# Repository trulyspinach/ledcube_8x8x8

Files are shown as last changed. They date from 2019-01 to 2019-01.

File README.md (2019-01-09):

# ledcube_8x8x8

Hobby Compact LED Cube.

Please beware that I'm not a professional electrical enginner, this project is just me having fun. I provide absolutely no warranty for this :)

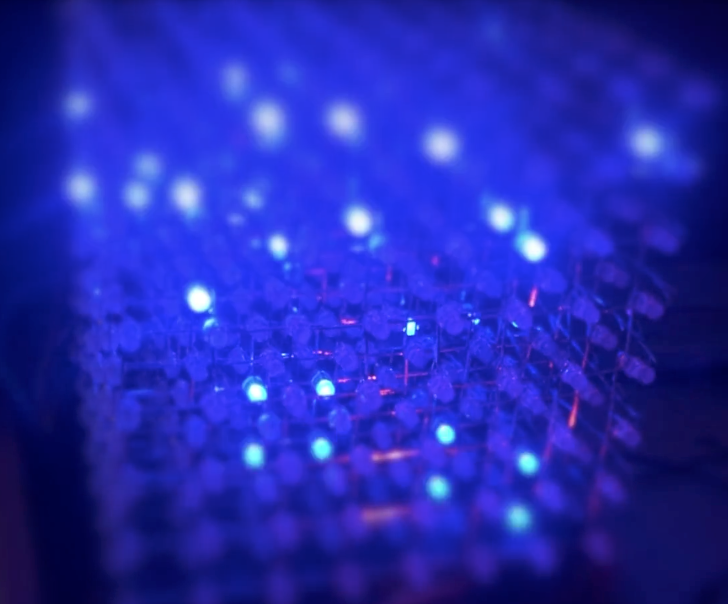
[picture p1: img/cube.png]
cover


## The hardware build

My goal is to build a compact LED cube. A lot of cube built i found on Internet is huge(kind of, at least you can't carry them with you), even when the resolution is 8x8x8. So I chose to use small LEDs, and a printed circuit board to hold them together while providing control circuits.

The microcontroller is Atmega32A, the reason of choosing AVR is just because they are simple and really cheap to get, and the 32A model have a fairly enough amount of pins available. Then eight 574s are used for multiplexing IOs. No big deals, pretty simple.

To build this, all you need is around 6 hundreds of LEDs. Only 512 are needed, but when you purchasing cheap LEDs, it is likely that some of them will malfunctions. And some resisitor, caps for the motherboard.

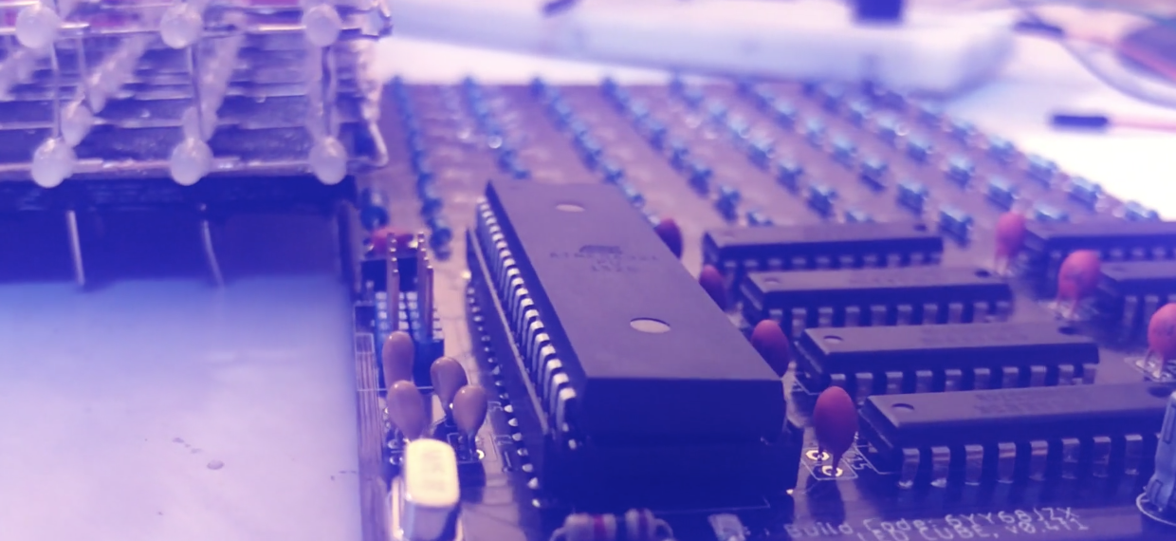
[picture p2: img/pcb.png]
pcb


I got all components on local stores and AliExpress, the complete built cost me less than $10(surprisingly cheap huh?).

## Software.

Well, since it is an Atmega32A, you can totaly program it using Arduino IDE(You don't need to).
I haven't had enough time to write some beautiful program yet, but the demo code included is just enough to test and proof your circuit is working.

Yes I will put more code here later..

## Did I made a video ?

Yes, it is here: https://www.bilibili.com/video/av40196289/

The voiceover is me speaking Chinese, but it should be fine.

## Where to get PCBs?

I did included all board layout file in the repo, you can export them with Eagle to some manufactor to made them.
As you know, those manufactors don't really like to just make one board, so I have some spare boards in my hand. I can ship one to you if you live in China, and if by the time you contact me I still have them..

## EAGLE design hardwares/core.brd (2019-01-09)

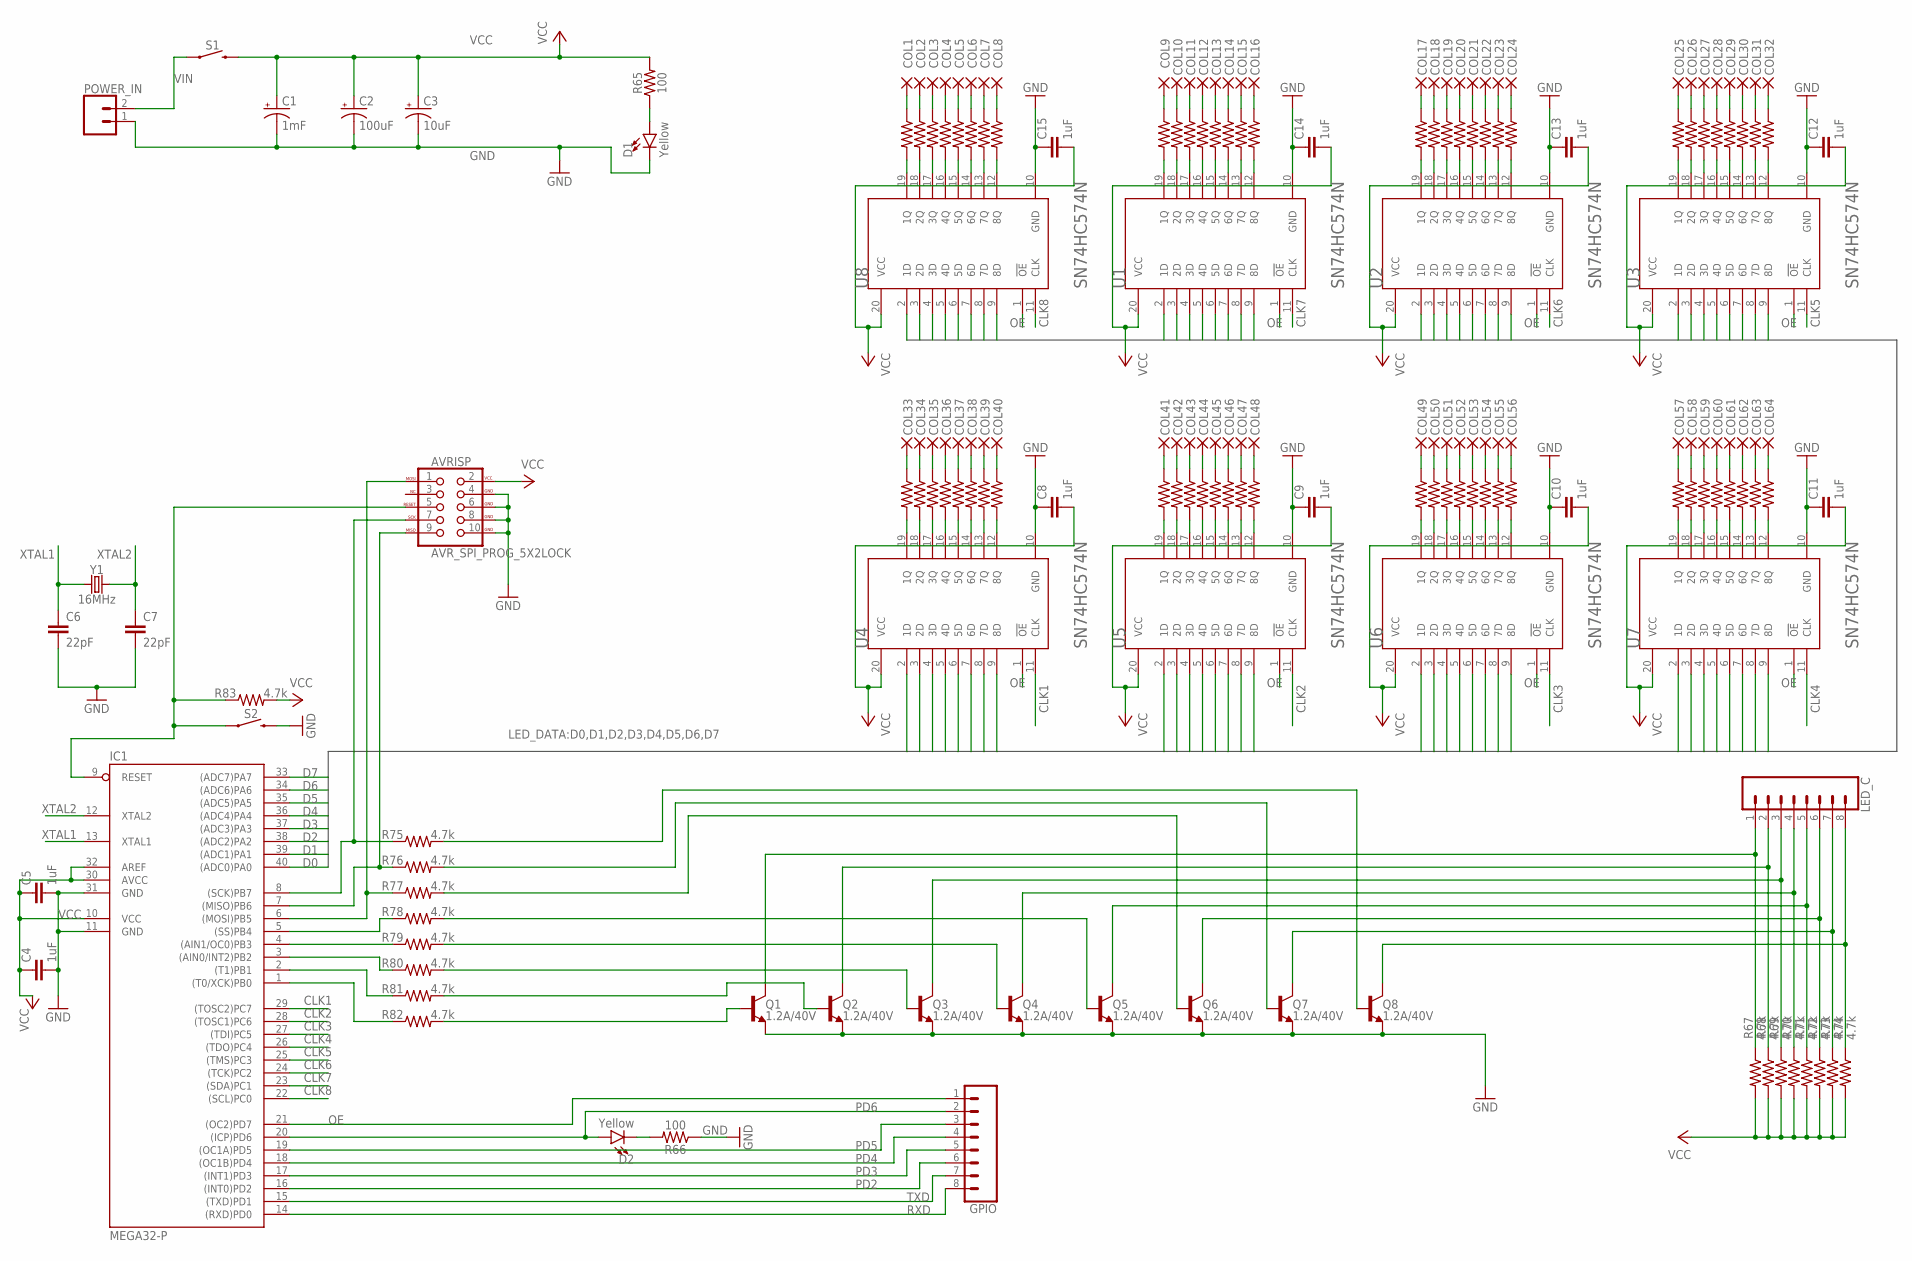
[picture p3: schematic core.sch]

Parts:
AVRISP: AVR_SPI_PROG_5X2LOCK; 2X5-SHROUDED_LOCK
C1: 1mF; CPOL-RADIAL-5MM-10MM
C2: 100uF; CPOL-RADIAL-2.5MM-6.5MM
C3: 10uF; CPOL-RADIAL-2.5MM-5MM
C4, C5, C8, C9, C10, C11, C12, C13, C14, C15: 1uF; C2.5-3
C6, C7: 22pF; CAP-PTH-2.54
COL1, COL2, COL3, COL4, COL5, COL6, COL7, COL8, COL9, COL10, COL11, COL12, COL13, COL14, COL15, COL16, COL17, COL18, COL19, COL20, COL21, COL22, COL23, COL24, COL25, COL26, COL27, COL28, COL29, COL30, COL31, COL32, COL33, COL34, COL35, COL36, COL37, COL38, COL39, COL40, COL41, COL42, COL43, COL44, COL45, COL46, COL47, COL48, COL49, COL50, COL51, COL52, COL53, COL54, COL55, COL56, COL57, COL58, COL59, COL60, COL61, COL62, COL63, COL64: 1,6/0,9
D1, D2: Yellow; LED-1206
GPIO: CONN_08"; 1X08
IC1: MEGA32-P; DIL40
LED_C: CONN_08"; 1X08
POWER_IN: CONN_02POLAR; MOLEX-1X2
Q1, Q2, Q3, Q4, Q5, Q6, Q7, Q8: 1.2A/40V; SOT23-3
R1, R2, R3, R4, R5, R6, R7, R8, R9, R10, R11, R12, R13, R14, R15, R16, R17, R18, R19, R20, R21, R22, R23, R24, R25, R26, R27, R28, R29, R30, R31, R32, R33, R34, R35, R36, R37, R38, R39, R40, R41, R42, R43, R44, R45, R46, R47, R48, R49, R50, R51, R52, R53, R54, R55, R56, R57, R58, R59, R60, R61, R62, R63, R64, R65, R66: 100; AXIAL-0.3
R67, R68, R69, R70, R71, R72, R73, R74, R75, R76, R77, R78, R79, R80, R81, R82, R83: 4.7k; AXIAL-0.3
S1: MOMENTARY-SWITCH-SPST-PTH-RIGHT-ANGLE-KIT; TACTILE_SWITCH_PTH_RIGHT_ANGLE_KIT
S2: MOMENTARY-SWITCH-SPST-PTH-6.0MM; TACTILE_SWITCH_PTH_6.0MM
U1, U2, U3, U4, U5, U6, U7, U8: TEXAS_INSTRUMENTS_SN74HC574NTEXAS_INSTRUMENTS_SN7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; TEXAS_INSTRUMENTS_SN74HC574N_0
Y1: 16MHz; HC49US

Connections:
CLK1: IC1.29 ((TOSC2)PC7), U4.11 (CLK)
CLK2: IC1.28 ((TOSC1)PC6), U5.11 (CLK)
CLK3: IC1.27 ((TDI)PC5), U6.11 (CLK)
CLK4: IC1.26 ((TDO)PC4), U7.11 (CLK)
CLK5: IC1.25 ((TMS)PC3), U3.11 (CLK)
CLK6: IC1.24 ((TCK)PC2), U2.11 (CLK)
CLK7: IC1.23 ((SDA)PC1), U1.11 (CLK)
CLK8: IC1.22 ((SCL)PC0), U8.11 (CLK)
D0: IC1.40 ((ADC0)PA0), U1.2 (1D), U2.2 (1D), U3.2 (1D), U4.2 (1D), U5.2 (1D), U6.2 (1D), U7.2 (1D), U8.2 (1D)
D1: IC1.39 ((ADC1)PA1), U1.3 (2D), U2.3 (2D), U3.3 (2D), U4.3 (2D), U5.3 (2D), U6.3 (2D), U7.3 (2D), U8.3 (2D)
D2: IC1.38 ((ADC2)PA2), U1.4 (3D), U2.4 (3D), U3.4 (3D), U4.4 (3D), U5.4 (3D), U6.4 (3D), U7.4 (3D), U8.4 (3D)
D3: IC1.37 ((ADC3)PA3), U1.5 (4D), U2.5 (4D), U3.5 (4D), U4.5 (4D), U5.5 (4D), U6.5 (4D), U7.5 (4D), U8.5 (4D)
D4: IC1.36 ((ADC4)PA4), U1.6 (5D), U2.6 (5D), U3.6 (5D), U4.6 (5D), U5.6 (5D), U6.6 (5D), U7.6 (5D), U8.6 (5D)
D5: IC1.35 ((ADC5)PA5), U1.7 (6D), U2.7 (6D), U3.7 (6D), U4.7 (6D), U5.7 (6D), U6.7 (6D), U7.7 (6D), U8.7 (6D)
D6: IC1.34 ((ADC6)PA6), U1.8 (7D), U2.8 (7D), U3.8 (7D), U4.8 (7D), U5.8 (7D), U6.8 (7D), U7.8 (7D), U8.8 (7D)
D7: IC1.33 ((ADC7)PA7), U1.9 (8D), U2.9 (8D), U3.9 (8D), U4.9 (8D), U5.9 (8D), U6.9 (8D), U7.9 (8D), U8.9 (8D)
GND: AVRISP.4 (GND), AVRISP.6 (GND), AVRISP.8 (GND), AVRISP.10 (GND), C1.-, C2.2 (-), C3.2 (-), C4.2, C5.2, C6.2, C7.2, C8.1, C9.1, C10.1, C11.1, C12.1, C13.1, C14.1, C15.1, D1.C, IC1.11 (GND), IC1.31 (GND), POWER_IN.1, Q1.2 (E), Q2.2 (E), Q3.2 (E), Q4.2 (E), Q5.2 (E), Q6.2 (E), Q7.2 (E), Q8.2 (E), R66.P$1 (1), S2.3 (2), U1.10 (GND), U2.10 (GND), U3.10 (GND), U4.10 (GND), U5.10 (GND), U6.10 (GND), U7.10 (GND), U8.10 (GND)
unnamed: COL1.1, R1.P$1 (1)
unnamed: R1.P$2 (2), U8.19 (1Q)
unnamed: COL2.1, R2.P$1 (1)
unnamed: R2.P$2 (2), U8.18 (2Q)
unnamed: COL3.1, R3.P$1 (1)
unnamed: R3.P$2 (2), U8.17 (3Q)
unnamed: COL4.1, R4.P$1 (1)
unnamed: R4.P$2 (2), U8.16 (4Q)
unnamed: COL5.1, R5.P$1 (1)
unnamed: R5.P$2 (2), U8.15 (5Q)
unnamed: COL6.1, R6.P$1 (1)
unnamed: R6.P$2 (2), U8.14 (6Q)
unnamed: COL7.1, R7.P$1 (1)
unnamed: R7.P$2 (2), U8.13 (7Q)
unnamed: COL8.1, R8.P$1 (1)
unnamed: R8.P$2 (2), U8.12 (8Q)
unnamed: COL9.1, R9.P$1 (1)
unnamed: R9.P$2 (2), U1.19 (1Q)
unnamed: COL10.1, R10.P$1 (1)
unnamed: R10.P$2 (2), U1.18 (2Q)
unnamed: COL11.1, R11.P$1 (1)
unnamed: R11.P$2 (2), U1.17 (3Q)
unnamed: COL12.1, R12.P$1 (1)
unnamed: R12.P$2 (2), U1.16 (4Q)
unnamed: COL13.1, R13.P$1 (1)
unnamed: R13.P$2 (2), U1.15 (5Q)
unnamed: COL14.1, R14.P$1 (1)
unnamed: R14.P$2 (2), U1.14 (6Q)
unnamed: COL15.1, R15.P$1 (1)
unnamed: R15.P$2 (2), U1.13 (7Q)
unnamed: COL16.1, R16.P$1 (1)
unnamed: R16.P$2 (2), U1.12 (8Q)
unnamed: COL17.1, R17.P$1 (1)
unnamed: R17.P$2 (2), U2.19 (1Q)
unnamed: COL18.1, R18.P$1 (1)
unnamed: R18.P$2 (2), U2.18 (2Q)
unnamed: COL19.1, R19.P$1 (1)
unnamed: R19.P$2 (2), U2.17 (3Q)
unnamed: COL20.1, R20.P$1 (1)
unnamed: R20.P$2 (2), U2.16 (4Q)
unnamed: COL21.1, R21.P$1 (1)
unnamed: R21.P$2 (2), U2.15 (5Q)
unnamed: COL22.1, R22.P$1 (1)
unnamed: R22.P$2 (2), U2.14 (6Q)
unnamed: COL23.1, R23.P$1 (1)
unnamed: R23.P$2 (2), U2.13 (7Q)
unnamed: COL24.1, R24.P$1 (1)
unnamed: R24.P$2 (2), U2.12 (8Q)
unnamed: COL25.1, R25.P$1 (1)
unnamed: R25.P$2 (2), U3.19 (1Q)
unnamed: COL26.1, R26.P$1 (1)
unnamed: R26.P$2 (2), U3.18 (2Q)
unnamed: COL27.1, R27.P$1 (1)
unnamed: R27.P$2 (2), U3.17 (3Q)
unnamed: COL28.1, R28.P$1 (1)
unnamed: R28.P$2 (2), U3.16 (4Q)
unnamed: COL29.1, R29.P$1 (1)
unnamed: R29.P$2 (2), U3.15 (5Q)
unnamed: COL30.1, R30.P$1 (1)
unnamed: R30.P$2 (2), U3.14 (6Q)
unnamed: COL31.1, R31.P$1 (1)
unnamed: R31.P$2 (2), U3.13 (7Q)
unnamed: COL32.1, R32.P$1 (1)
unnamed: R32.P$2 (2), U3.12 (8Q)
unnamed: COL33.1, R33.P$1 (1)
unnamed: R33.P$2 (2), U4.19 (1Q)
unnamed: COL34.1, R34.P$1 (1)
unnamed: R34.P$2 (2), U4.18 (2Q)
unnamed: COL35.1, R35.P$1 (1)
unnamed: R35.P$2 (2), U4.17 (3Q)
unnamed: COL36.1, R36.P$1 (1)
unnamed: R36.P$2 (2), U4.16 (4Q)
unnamed: COL37.1, R37.P$1 (1)
unnamed: R37.P$2 (2), U4.15 (5Q)
unnamed: COL38.1, R38.P$1 (1)
unnamed: R38.P$2 (2), U4.14 (6Q)
unnamed: COL39.1, R39.P$1 (1)
unnamed: R39.P$2 (2), U4.13 (7Q)
unnamed: COL40.1, R40.P$1 (1)
unnamed: R40.P$2 (2), U4.12 (8Q)
unnamed: COL41.1, R41.P$1 (1)
unnamed: R41.P$2 (2), U5.19 (1Q)
unnamed: COL42.1, R42.P$1 (1)
unnamed: R42.P$2 (2), U5.18 (2Q)
unnamed: COL43.1, R43.P$1 (1)
unnamed: R43.P$2 (2), U5.17 (3Q)
unnamed: COL44.1, R44.P$1 (1)
unnamed: R44.P$2 (2), U5.16 (4Q)
unnamed: COL45.1, R45.P$1 (1)
unnamed: R45.P$2 (2), U5.15 (5Q)
unnamed: COL46.1, R46.P$1 (1)
unnamed: R46.P$2 (2), U5.14 (6Q)
unnamed: COL47.1, R47.P$1 (1)
unnamed: R47.P$2 (2), U5.13 (7Q)
unnamed: COL48.1, R48.P$1 (1)
unnamed: R48.P$2 (2), U5.12 (8Q)
unnamed: COL49.1, R49.P$1 (1)
unnamed: R49.P$2 (2), U6.19 (1Q)
unnamed: COL50.1, R50.P$1 (1)
unnamed: R50.P$2 (2), U6.18 (2Q)
unnamed: COL51.1, R51.P$1 (1)
unnamed: R51.P$2 (2), U6.17 (3Q)
unnamed: COL52.1, R52.P$1 (1)
unnamed: R52.P$2 (2), U6.16 (4Q)
unnamed: COL53.1, R53.P$1 (1)
unnamed: R53.P$2 (2), U6.15 (5Q)
unnamed: COL54.1, R54.P$1 (1)
unnamed: R54.P$2 (2), U6.14 (6Q)
unnamed: COL55.1, R55.P$1 (1)
unnamed: R55.P$2 (2), U6.13 (7Q)
unnamed: COL56.1, R56.P$1 (1)
unnamed: R56.P$2 (2), U6.12 (8Q)
unnamed: COL57.1, R57.P$1 (1)
unnamed: R57.P$2 (2), U7.19 (1Q)
unnamed: COL58.1, R58.P$1 (1)
unnamed: R58.P$2 (2), U7.18 (2Q)
unnamed: COL59.1, R59.P$1 (1)
unnamed: R59.P$2 (2), U7.17 (3Q)
unnamed: COL60.1, R60.P$1 (1)
unnamed: R60.P$2 (2), U7.16 (4Q)
unnamed: COL61.1, R61.P$1 (1)
unnamed: R61.P$2 (2), U7.15 (5Q)
unnamed: COL62.1, R62.P$1 (1)
unnamed: R62.P$2 (2), U7.14 (6Q)
unnamed: COL63.1, R63.P$1 (1)
unnamed: R63.P$2 (2), U7.13 (7Q)
unnamed: COL64.1, R64.P$1 (1)
unnamed: R64.P$2 (2), U7.12 (8Q)
unnamed: D1.A, R65.P$1 (1)
unnamed: D2.C, R66.P$2 (2)
unnamed: LED_C.1, Q1.3 (C), R67.P$1 (1)
unnamed: LED_C.2, Q2.3 (C), R68.P$1 (1)
unnamed: LED_C.3, Q3.3 (C), R69.P$1 (1)
unnamed: LED_C.4, Q4.3 (C), R70.P$1 (1)
unnamed: LED_C.5, Q5.3 (C), R71.P$1 (1)
unnamed: LED_C.6, Q6.3 (C), R72.P$1 (1)
unnamed: LED_C.7, Q7.3 (C), R73.P$1 (1)
unnamed: LED_C.8, Q8.3 (C), R74.P$1 (1)
unnamed: IC1.1 ((T0/XCK)PB0), R82.P$1 (1)
unnamed: IC1.2 ((T1)PB1), R81.P$1 (1)
unnamed: IC1.3 ((AIN0/INT2)PB2), R80.P$1 (1)
unnamed: IC1.4 ((AIN1/OC0)PB3), R79.P$1 (1)
unnamed: IC1.5 ((SS)PB4), R78.P$1 (1)
unnamed: AVRISP.1 (MOSI), IC1.6 ((MOSI)PB5), R77.P$1 (1)
unnamed: AVRISP.9 (MISO), IC1.7 ((MISO)PB6), R76.P$1 (1)
unnamed: AVRISP.7 (SCK), IC1.8 ((SCK)PB7), R75.P$1 (1)
unnamed: Q1.1 (B), R82.P$2 (2)
unnamed: Q2.1 (B), R81.P$2 (2)
unnamed: Q6.1 (B), R77.P$2 (2)
unnamed: Q3.1 (B), R80.P$2 (2)
unnamed: Q4.1 (B), R79.P$2 (2)
unnamed: Q5.1 (B), R78.P$2 (2)
unnamed: Q7.1 (B), R76.P$2 (2)
unnamed: Q8.1 (B), R75.P$2 (2)
unnamed: AVRISP.5 (RESET), IC1.9 (RESET), R83.P$1 (1), S2.1
OE: GPIO.1, IC1.21 ((OC2)PD7), U1.1 (!OE!), U2.1 (!OE!), U3.1 (!OE!), U4.1 (!OE!), U5.1 (!OE!), U6.1 (!OE!), U7.1 (!OE!), U8.1 (!OE!)
PD2: GPIO.6, IC1.16 ((INT0)PD2)
PD3: GPIO.5, IC1.17 ((INT1)PD3)
PD4: GPIO.4, IC1.18 ((OC1B)PD4)
PD5: GPIO.3, IC1.19 ((OC1A)PD5)
PD6: D2.A, GPIO.2, IC1.20 ((ICP)PD6)
RXD: GPIO.8, IC1.14 ((RXD)PD0)
TXD: GPIO.7, IC1.15 ((TXD)PD1)
VCC: AVRISP.2 (VCC), C1.+, C2.1 (+), C3.1 (+), C4.1, C5.1, C8.2, C9.2, C10.2, C11.2, C12.2, C13.2, C14.2, C15.2, IC1.10 (VCC), IC1.30 (AVCC), IC1.32 (AREF), R65.P$2 (2), R67.P$2 (2), R68.P$2 (2), R69.P$2 (2), R70.P$2 (2), R71.P$2 (2), R72.P$2 (2), R73.P$2 (2), R74.P$2 (2), R83.P$2 (2), S1.2, U1.20 (VCC), U2.20 (VCC), U3.20 (VCC), U4.20 (VCC), U5.20 (VCC), U6.20 (VCC), U7.20 (VCC), U8.20 (VCC)
VIN: POWER_IN.2, S1.1
XTAL1: C6.1, IC1.13 (XTAL1), Y1.1
XTAL2: C7.1, IC1.12 (XTAL2), Y1.2

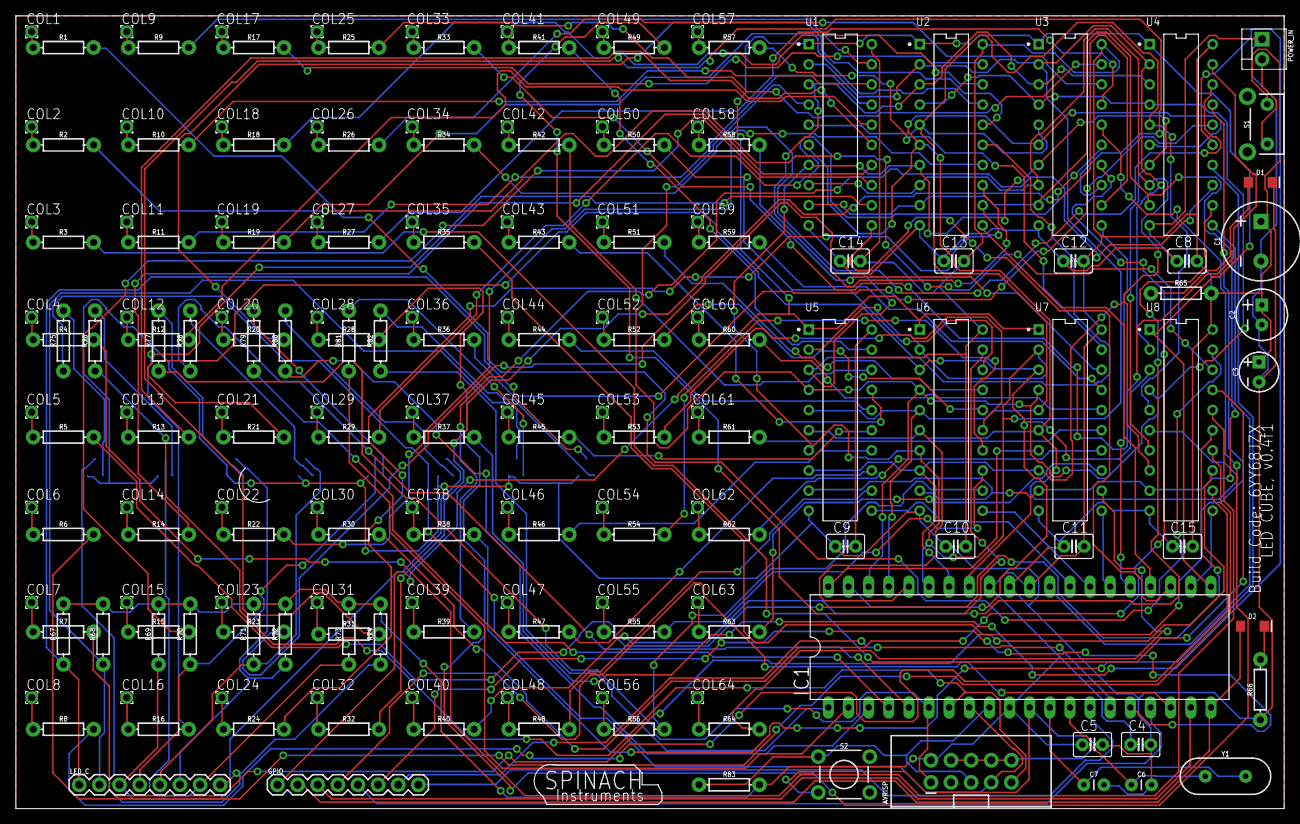
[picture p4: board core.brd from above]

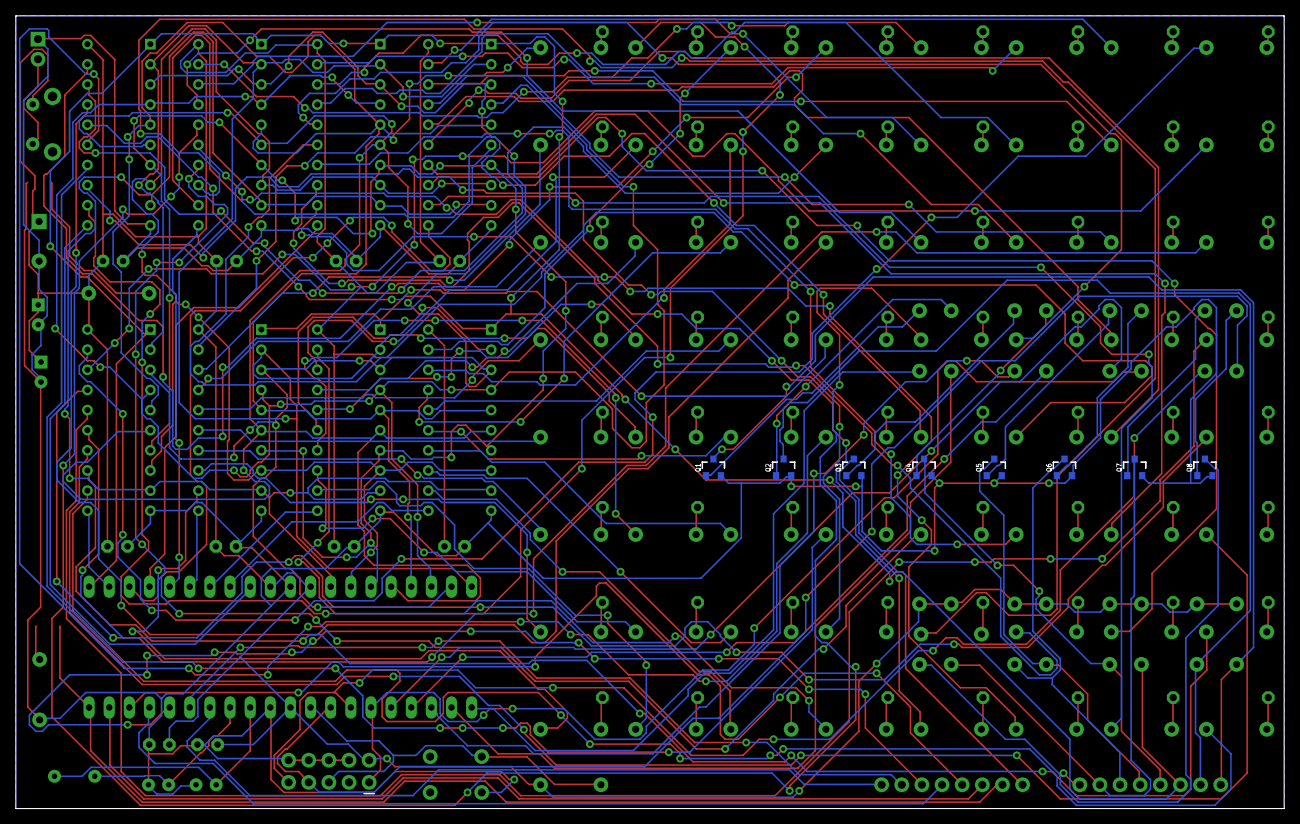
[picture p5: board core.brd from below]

Board: 2 copper layers, 160.0 x 100.0 mm, 188 parts (8 on the bottom side), 184 nets.

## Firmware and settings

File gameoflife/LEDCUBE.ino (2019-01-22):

extern "C"
{
  #include "cube.h"
  #include "cube_graphics.h"
  #include "gameoflife.h"
}


void setup() {
  pinMode(14, OUTPUT);
  pinMode(15, OUTPUT);

  randomSeed(analogRead(0));

  flash_startup_indic();

  init_cube();

  Serial.begin(115200);
  //Set default brightness for cube.
  //analogWrite(15, 210);


  Serial.println("Cube alive!");
  // noise_on();
  // noise_off();
  //
  // rain();

  rand_gen();
  //test_two();
}

void loop(){
  tick();
  //delay(200);
}

void print_coor(uint8_t x, uint8_t y, uint8_t z){
  Serial.print(x);
  Serial.print(", ");
  Serial.print(y);
  Serial.print(", ");
  Serial.println(z);
}



//########## Effects ###########




void voxel_test(){

  Serial.println("voxel test");

  fill_vram();
  uint8_t x = 0;
  uint8_t y = 0;
  uint8_t z = 0;

  bool s_reset = true;

  while(1){
    if(s_reset == false && x == 7 && y == 7 && z == 7) break;
    if(s_reset) reset_voxel(x++,y,z);
    else set_voxel(x++, y, z);
    if(x >= 8){x = 0; y++;}
    if(y >= 8){y = 0; z++;}
    if(z >= 8){z = 0; s_reset = !s_reset;}
    delay(2);

  }
}

void voxel_test_bit(){
  uint16_t remain = 0;

  Serial.println("bit test");
  reset_vram();

  while(remain < 512){
    vram_bit_set(remain++);
    //Serial.println(vram_bit_get(remain++));
    delay(2);
  }
}

void noise_on(){
  reset_vram();
  uint16_t rmn = 512;

  while(rmn > 0){
    uint16_t t_offset = random(1,rmn--);
    uint16_t t_c = 0; uint16_t index = 0;
    while(t_c != t_offset){
       if(vram_bit_get(index++)) continue;
       t_c++;
    }
    vram_bit_set(index - 1);

    //delay(2);
  }
}



void noise_off(){
  uint16_t rmn = 512;

  while(rmn > 0){
    uint16_t t_offset = random(1,rmn--);
    uint16_t t_c = 0; uint16_t index = 0;
    while(t_c != t_offset){
       if(!vram_bit_get(index++)) continue;
       t_c++;
    }
    vram_bit_reset(index - 1);

    //delay(2);
  }
}

void rain(){
  reset_vram();
  uint8_t t = 50;
  while(t-- > 0){
    for(uint8_t i = 0; i < 8; i++)
      vram[i] = 0x00;

    random_on(random(1,8),64);
    vram_shift_down();

    delay(60);
  }

}

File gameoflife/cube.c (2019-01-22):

#include <arduino.h>
#include <avr/io.h>
#include <avr/interrupt.h>
#include <stdbool.h>

#include "cube.h"

uint8_t default_vram[64] = {
  0xff, 0xff, 0xff, 0xff, 0xff, 0xff, 0xff, 0xff,
  0xff, 0xff, 0xff, 0xff, 0xff, 0xff, 0xff, 0xff,
  0xff, 0xff, 0xff, 0xff, 0xff, 0xff, 0xff, 0xff,
  0xff, 0xff, 0xff, 0xff, 0xff, 0xff, 0xff, 0xff,
  0xff, 0xff, 0xff, 0xff, 0xff, 0xff, 0xff, 0xff,
  0xff, 0xff, 0xff, 0xff, 0xff, 0xff, 0xff, 0xff,
  0xff, 0xff, 0xff, 0xff, 0xff, 0xff, 0xff, 0xff,
  0xff, 0xff, 0xff, 0xff, 0xff, 0xff, 0xff, 0xff
};

uint8_t* vram;

uint8_t vram_addr_map[8] = {
  0x01, 0x02, 0x04, 0x08, 0x80, 0x40, 0x20, 0x10
};

//########## Cube refresh routine. ##########

void init_vram(){
  vram = default_vram;
}

void swap_vram(uint8_t ram){
  vram = ram;
}

void setup_refresh_task(){
  TCCR1A = 0x0;
  TCCR1B = 0x3 | _BV(WGM12);
  OCR1A = 0xff;
  TIMSK |= _BV(OCIE1A);

  sei();
}

uint8_t cur_layer = 0;
//Timer interrupt routine to switch layers at constant time interval.
ISR(TIMER1_COMPA_vect){
  PORTC = 0x00;
  for(uint8_t i = 0; i < 8; i++){
    PORTA = vram[cur_layer * 8 + i];
    delayMicroseconds(1);
    PORTC = vram_addr_map[i];
    delayMicroseconds(1);
    PORTC = 0x00;
  }

  PORTB = 1 << cur_layer;
  delayMicroseconds(70);
  PORTB = 0;

  cur_layer++;
  if(cur_layer >= 8) cur_layer = 0;

}

//########## Cube refresh routine. ##########

//########## Low level graphic. #########

void g_set_voxel(uint8_t* ram, uint8_t x, uint8_t y, uint8_t z){
  uint8_t addr = (z % 8) * 8 + (y % 8);
  ram[addr] |= 1 << (x % 8);
}

void g_reset_voxel(uint8_t* ram, uint8_t x, uint8_t y, uint8_t z){
  uint8_t addr = (z % 8) * 8 + (y % 8);
  ram[addr] &= ~(1 << (x % 8));
}

uint8_t g_get_voxel(uint8_t* ram, uint8_t x, uint8_t y, uint8_t z){
  uint8_t addr = (z % 8) * 8 + (y % 8);
  return (ram[addr] >> x) & 0x01;
}

void set_voxel(uint8_t x, uint8_t y, uint8_t z){
  g_set_voxel(vram, x, y, z);
}

void reset_voxel(uint8_t x, uint8_t y, uint8_t z){
  g_reset_voxel(vram, x, y, z);
}

uint8_t get_voxel(uint8_t x, uint8_t y, uint8_t z){
  uint8_t res = g_get_voxel(vram, x, y, z);
  return res;
}

void reset_vram(){
  for(uint8_t i = 0; i < 64; i++)
    vram[i] = 0x00;
}

void fill_vram(){
  for(uint8_t i = 0; i < 64; i++)
    vram[i] = 0xff;
}

void vram_bit_set(uint16_t index){
  set_voxel(index % 8, (index % 64) / 8, index / 64);
}

void vram_bit_reset(uint16_t index){
  reset_voxel(index % 8, (index % 64) / 8, index / 64);
}

uint8_t vram_bit_get(uint16_t index){
  return get_voxel(index % 8, (index % 64) / 8, index / 64);
}

void vram_shift_down(){
  uint8_t carry[8];
  for(uint8_t i = 0; i < 8; i++) carry[i] = vram[8*7 + i];

  for(uint8_t i = 0; i < 8; i++){
    for(uint8_t j = 0; j < 8; j++){
      uint8_t cache = vram[i * 8 + j];
      vram[i * 8 + j] = carry[j];
      carry[j] = cache;
    }
  }
}

//########## Low level graphic. #########

bool ledOn = 0;

void flash_startup_indic(){
  for(int i = 0; i < 5;i++){
    digitalWrite(14, HIGH);
    delay(35);
    digitalWrite(14, LOW);
    delay(35);
  }
  digitalWrite(14, HIGH);
}

void init_cube(){
  DDRA = 0xff; DDRB = 0xff; DDRC = 0xff;

  PORTA = 0xff;
  PORTB = 0x00; //Turn all layers display off.

  PORTC = 0x00;
  PORTC = 0xff;

  //Write to all vram chip.
  PORTC = 0x00;
  delayMicroseconds(1);
  PORTC = 0xff;

  //Reset clock bus
  PORTC = 0x00;

  init_vram();
  setup_refresh_task();
}

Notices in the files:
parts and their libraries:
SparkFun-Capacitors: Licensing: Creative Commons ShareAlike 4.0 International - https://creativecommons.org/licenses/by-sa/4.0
